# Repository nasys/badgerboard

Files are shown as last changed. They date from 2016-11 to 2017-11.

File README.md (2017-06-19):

				 ___               _                      _                             _
				(  _`\            ( )                    ( )                           ( )
				| (_) )   _ _    _| |   __     __   _ __ | |_      _      _ _  _ __   _| |
				|  _ <' /'_` ) /'_` | /'_ `\ /'__`\( '__)| '_`\  /'_`\  /'_` )( '__)/'_` |
				| (_) )( (_| |( (_| |( (_) |(  ___/| |   | |_) )( (_) )( (_| || |  ( (_| |
			    (____/'`\__,_)`\__,_)`\__  |`\____)(_)   (_,__/'`\___/'`\__,_)(_)  `\__,_)
									 ( )_) |
								 	  \___/'
============================

### **Table of Contents**
 * [Prerequisites](#prerequisites)
 	* [Downloads](#downloads)
	* [General installation](#general-installation)
 	* [Mac OS X installation with Git](#mac-os-x-installation-with-git)
 	* [Windows installation with Git](#windows-installation-with-git)
 * [Badgerboard Setup](#badgerboard-setup)
	* [Test out your Badgerboard](#test-out-your-badgerboard) 
 	* [LoRa sensor setup](#lora-sensor-setup)
 * [Debugging](#debugging)
 * [Known issues](#known-issues)
 * [Version log](#version-log)
 * [Used libraries](#used-libraries)
 * [Licences](#licences)

### Prerequisites

##### Downloads

* [**Arduino**](https://www.arduino.cc/en/Main/Software)
* [**Git**](https://git-scm.com/book/en/v2/Getting-Started-Installing-Git)

#### General installation
* [Download](https://github.com/nasys/badgerboard/archive/master.zip) this library as **.zip** file

now this file is in downloads folder named Badgerboard-master.zip

* Open Arduino and include it under **Sketch -> Include library -> add .zip library**

##### Mac OS X installation with Git

* Open "**Finder**" (Press &#8984;+ Space ) 
* type in "terminal" and open it
* type "cd Documents/Arduino/libraries"
* type "git clone https://github.com/nasys/badgerboard"
* Now when you open up your Arduino and _Badgerboard_ library should appear under **Sketch -> Include library**

##### Windows installation with Git

Coming soon

### **Badgerboard setup**
#### Test out your Badgerboard
```diff
- DO NOT POWER ON WITHOUT ANTENNA! 

```

* Make sure Badgerboard power switch is turned ON ([button towards USB port](https://www.maker.io/-/media/makerio/makerimages/blogs/badgerboard/badgerboard-figure-1.jpg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))
* connect Badgerboard to your PC/Mac 
* Open Arduino
* Open Blink example **Files -> Examples -> 01.Basics -> Blink**
* Make sure you have chosen correct board  **Tools -> Board -> LilyPad Arduino USB** and correct port **Tools -> Port** 
* Change the time(number in milliseconds) inside the brackets after "**delay**" to change the speed of blinking
* To **upload** click on the __right pointing arrow__ on the top-left corner of your Arduino window

In case all of this works then you have successfully uploaded your first program to Badgerboard

#### LoRa sensor setup

* Open **File -> Examples -> Badgerboard -> LoRa_temp_hum**
* Replace examples **devEUI**(16 hex char), **appEUI**(16 hex char) and **appKey**(32 hex char) with the ones that Your LoRaWAN™ solution provider has assigned.([example 1](#example-1)) 
* Upload Your code to Badgerboard

##### example 1

	In Arduino code your devEUI, appEUI and appKey are represented by char array and should look similar to 
	this example
	
	const uint8_t devEUI[8] = {
	0x11, 0x11, 0x22, 0x22,
	0x33, 0x33, 0x44, 0x44
	};

	const uint8_t appKey[16] = {
	0x11, 0x11, 0x11, 0x11,
	0x11, 0x11, 0x22, 0x22,
	0x22, 0x22, 0x22, 0x22,
	0x33, 0x33, 0x33, 0x33
	};

	const uint8_t appEUI[8] = {
	0x11, 0x22, 0x33, 0x44,
	0x55, 0x66, 0x77, 0x88
	};

### Debugging

To see Debugging messages open Serial Monitor **Tools -> Serial Monitor**
#### Known issues

* Take a look under [troubleshooting](https://github.com/nasys/badgerboard/wiki/Troubleshooting) page
* Works only with Arduino version 1.6.10 and later

### Version log

#### Version 0.0.3
	* Added a quickfix related to SF not changeing
	* Added _mod to library names to avoid issues if libraries are already installed
	
#### Version 0.0.2
:calendar:06.12.2016

	* Changed spreading factor changing to automatic
	* Added liquid detection example 

#### Version 0.0.1
:calendar:01.11.2016 

	Initial version of Badgerboard library

#### Used libraries
* [**FaBoHumidity_HTS221**](https://github.com/FaBoPlatform/FaBoHumidity-HTS221-Library)
* [**LowPower**](https://github.com/rocketscream/Low-Power)
* [**Sodaq_RN2483**](https://github.com/SodaqMoja/Sodaq_RN2483)

### **Licences**

All of the source files are distributed under the beerware license except where specified otherwise (i.e. external libraries)
 
#### Contacts
In case you found the instructions incomplete or have any questions regarding Badgerboard library
You can :
* Open new thread under [issues](https://github.com/nasys/badgerboard/issues)
* :e-mail: [contact us](mailto:badgerboard@nasys.no)

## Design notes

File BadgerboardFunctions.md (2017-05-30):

* **badger_init()** -  Mandatory to use badgerboard library.

* ****badger_temp_hum_get(float* temp, float* hum)** - Returns onboard temperature and humidity sensor readings. 

**e.g** 

      void loop() 
        {
          static float temp = 0;
          static float hum = 0;
          badger_temp_hum_get(&temp,&hum);
          Serial.print("temperature  :  ");
          Serial.println(temp);
          Serial.print("humidity  :  ");
          Serial.println(hum);
          delay(4000);
        }

* **Lora_requires_reset()** - If failed packets is greater than 10(_in a row not total_) this function returns true
**_reccommended to use with badger_restart()_**.

* **LoRa_init(const uint8_t dev_EUI[8], const uint8_t app_EUI[8], const uint8_t app_Key[16])** -  Starts communication with LoRa module
**_devEUI, appkey and appEUI_** have to be previously defined.

**e.g**.

        const uint8_t devEUI[8] = {
        0x87, 0x65, 0x43, 0x23,
        0x45, 0x67, 0x87, 0x65
        };

       const uint8_t appKey[16] = {
        0x76, 0x54, 0x32, 0x34,
        0x56, 0x78, 0x98, 0x76,
        0x54, 0x32, 0x23, 0x45,
        0x67, 0x87, 0x65, 0x43
        };

       const uint8_t appEUI[8] = {
       0x65, 0x43, 0x23, 0x45,
       0x67, 0x88, 0x76, 0x54
       };

        void setup()
        {
            badger_init();
           LoRa_init(devEUI, appEUI, appKey);
        }

* **badger_print_EUI(const uint8_t dev_EUI[8])** - Prints devEUI to serial monitor.

* ***LoRa_send(uint8_t fPort, const uint8_t* data, uint8_t len)** - User can use this function to send custom information to custom port.

* ***LoRa_send(uint8_t fPort, const uint8_t* data, uint8_t len, int8_t send_count)** - User can use this function to send custom information to custom port ( send_count defines ammount of retries ).

* **badger_temp_sensor_send()** - Sends temperature and humidity to port 19 as **_JSON_**.

* **badger_hum_send()** - Sends onboard humidity sensor readings to port 4.

* **badger_temp_send()** - Sends onboard temperature sensor readings to port 1.

* **LoRa_add_sensitivity(uint8_t sensitivity)**  - User can force LoRa to use different spreading factor
_example_ is under **file &rarr; Examples &rarr; Badgerboard &rarr; LoRa_sf_change**. This example waits for user numeric input to Serial Monitor from **1 to 6** which change spreading factor correspondingly from **7 to 12**.

* **badger_temp_sensor_send_status(uint8_t status)** - Sends temperature, humidity and voltage readings to port 19 as JSON (gives user opportunity to send custom bytes as status).

* **badger_read_vcc_mv()** - Returns **MCU** LDO regulated supply voltage in milliVolts (not actual battery/external power supply voltage), usually 3300 mV. Useful for end of battery detection.

* **badger_restart()** - Restarts Badgerboard.

* **sendCayanneTempHum()** - Send Cayanne standard packet with temperature and humidity .

* **badger_sleep_now(uint32_t period_ms)** - Put badger to sleep for period_ms on **WDT**.

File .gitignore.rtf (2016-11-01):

# gitignore

.DS_Store
info.plist
scm.plist
text-filter.idx
text-find.idx

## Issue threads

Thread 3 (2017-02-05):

Included copies of FaBo HTS221 and LowPower libraries break compiling of sketches that use the originals

avbentem, 2017-02-05:
The Badgerboard core library includes a copy of https://github.com/FaBoPlatform/FaBoHumidity-HTS221-Library When compiling unrelated other sketches that rely on that library, in an Arduino IDE into which the Badgerboard library has been installed as well (but which do not use the Badgerboard library in the sketch), I get:

    libraries/badgerboard/badger.cpp.o (symbol from plugin): In function `sodaq_wdt_enable(wdt_period)':
    (.text+0x0): multiple definition of `faboHumidity'
    sketch/humidity.ino.cpp.o (symbol from plugin):(.text+0x0): first defined here
    collect2: error: ld returned 1 exit status
    Multiple libraries were found for "FaBoHumidity_HTS221.h"
    Used: /Users/arjan/Arduino/libraries/badgerboard
    Not used: /Users/arjan/Arduino/libraries/FaBo_208_Humidity_HTS221

Also, someone else commented on The Things Network that the same applied to https://github.com/rocketscream/Low-Power:

> I got errors compiling older sketches after installing the badgerboard library because they included some kind of incompatible LowPower library. I had to remove the badgerboard/src/lowpower.h and badgerboard/src/lowpower.cpp file to get my old sketches to work again.

This makes me wonder if it might also apply to https://github.com/SodaqMoja/Sodaq_RN2483

Renaming the copies will probably solve the issue?

Kakuke001, 2017-02-08:
Hi,

Changed the library names (added **_mod**) to fix this issue

Closed 2017-10-09.

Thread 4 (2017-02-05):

Getting "LoRa: warning. Spreading factor not set!", "LoRa: power not set!", "LoRa: datarate not set!"

avbentem, 2017-02-05:
When the first OTAA join fails, the Badgerboard library states:

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

Same for SF11, but not for SF10. EU868.

Kakuke001, 2017-02-08:
Hi,

Uploaded new commit where **LoRa_add_sensitivity()** has now **LoRaBee.wakeUp()** function...right now as a quick fix to this problem i added **LoRaBee.wakeUp()** twice which seemed to fix the problem....i try to get to the bottom of this problem soon

qvs5010, 2018-01-19:
where do you add that to the sketch

i get the same from the Lora_temp_hum sketch.

```
Lora: Adding sensitivity: SF 8
LoRa: warning. Spreading factor not set!
LoRa: power not set!
LoRa: datarate not set!
Lora: Adding sensitivity: SF 9
LoRa: warning. Spreading factor not set!
LoRa: power not set!
LoRa: datarate not set!
Lora: Adding sensitivity: SF 10
LoRa: warning. Spreading factor not set!
LoRa: power not set!
LoRa: datarate not set!
Booting failed.
Badger attempting to restart

```

qvs5010, 2018-01-19:
Ok think I found it

badger.cpp?

But still the same problem

```
bool LoRa_add_sensitivity(uint8_t sensitivity)
{
	LoRaBee.wakeUp();
	LoRaBee.wakeUp();
	sensitivity = sensitivity - 1;
	if(sensitivity > 6)
		sensitivity = 6;
	sensitivity = 5 - sensitivity;
	Serial.print("Lora: Adding sensitivity: SF ");
	Serial.println(12 - sensitivity);
	bool ok = LoRaBee.setSpreadingFactor(12 - sensitivity);
	ok = LoRaBee.setTXPower(15) && ok;
	ok = LoRaBee.setDataRate(sensitivity) && ok;
	return ok;
	}
```

```
Configured onboard temp/humidity sensor.
badger temp/hum sensor
devEUI XX XX XX XX XX
Lora: Adding sensitivity: SF -243
LoRa: Spreading factor set to 12
LoRa: power set to 15
LoRa: datarate not set!
Lora: Adding sensitivity: SF 7
LoRa: Spreading factor set to 7
LoRa: power set to 15
LoRa: datarate set to 5
Lora: Adding sensitivity: SF 8
LoRa: warning. Spreading factor not set!
LoRa: power not set!
LoRa: datarate not set!
Lora: Adding sensitivity: SF 9
LoRa: warning. Spreading factor not set!
LoRa: power not set!
LoRa: datarate not set!
Lora: Adding sensitivity: SF 10
LoRa: warning. Spreading factor not set!
LoRa: power not set!
LoRa: datarate not set!

```

KertIlm, 2018-01-22:
Hi qvs5010,

When did you download Badgerboard library ?
I tried it out but i don't have problem with it ... try downloading the latest library and then try it again.

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

qvs5010, 2018-01-22:
Hi got the badgerbord on Friday, and I downloaded the library from this git hub

https://github.com/nasys/badgerboard/archive/master.zip

I followed the instructions as indicated.

can you email me you library and I can try?

Thanks for the help

KertIlm, 2018-01-22:
Hello again!

I uninstalled my Arduino IDE and downloaded it again(downloaded zip file from the link you provided so there is no version difference) ... also tried it on a windows pc ... all seems to work ... try uninstalling Arduino and download the latest version.

qvs5010, 2018-01-22:
Hi
I' trying now on a new machine, downloading all files again, will update you soon

qvs5010, 2018-01-22:
Hi Still does the same

New Machine, new IDE, new Library

```
Lora: Adding sensitivity: SF 7
LoRa: Spreading factor set to 7
LoRa: power set to 15
LoRa: datarate set to 5
Lora: Adding sensitivity: SF 8
LoRa: warning. Spreading factor not set!
LoRa: power not set!
LoRa: datarate not set!
```

```
Quintins-MBP:libraries quintin$ git clone https://github.com/nasys/badgerboard
Cloning into 'badgerboard'...
remote: Counting objects: 546, done.
remote: Total 546 (delta 0), reused 0 (delta 0), pack-reused 546
Receiving objects: 100% (546/546), 670.95 KiB | 184.00 KiB/s, done.
Resolving deltas: 100% (297/297), done.
```

is it hardware related?

qvs5010, 2018-01-22:
Hi
Tried another pc, the same...

I'm going to cry in the conner,
 :'(

KertIlm, 2018-01-22:
are you using badgerboard example program or your own custom code ? ... All my tests were done on **Lora_temp_hum** exmple.

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

qvs5010, 2018-01-22:
Hi

Yes I load the example directly.

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

qvs5010, 2018-01-22:
Hi

I tried to add more LoRaBee.wakeUp(); to the LoRa_add_sensitivity(uint8_t sensitivity) function, to make it look like the following.

```
bool LoRa_add_sensitivity(uint8_t sensitivity)
{
	LoRaBee.wakeUp();
	LoRaBee.wakeUp();
	LoRaBee.wakeUp();
	LoRaBee.wakeUp();
	sensitivity = sensitivity - 1;
	if(sensitivity > 6)
		sensitivity = 6;
	sensitivity = 5 - sensitivity;
	Serial.print("Lora: Adding sensitivity: SF ");
	Serial.println(12 - sensitivity);
	bool ok = LoRaBee.setSpreadingFactor(12 - sensitivity);
	ok = LoRaBee.setTXPower(15) && ok;
	ok = LoRaBee.setDataRate(sensitivity) && ok;
	return ok;
	}
```

must I compile the cpp file after changing or will the IDE do that?

qvs5010, 2018-01-22:
Hi

Even with the extra LoRaBee.wakeUp(); still the same

```
Configured onboard temp/humidity sensor.
badger temp/hum sensor
devEUI 11 11 22 22 33 33 44 44
Lora: Adding sensitivity: SF -243
LoRa: Spreading factor set to 12
LoRa: power set to 15
LoRa: datarate not set!
Lora: Adding sensitivity: SF 7
LoRa: Spreading factor set to 7
LoRa: power set to 15
LoRa: datarate set to 5
Lora: Adding sensitivity: SF 8
LoRa: warning. Spreading factor not set!
LoRa: power not set!
LoRa: datarate not set!
```

KertIlm, 2018-01-22:
Have you chosen **LilyPad Arduino USB** as board

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

qvs5010, 2018-01-22:
Hi

yes, I'm the Lilly USB

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

qvs5010, 2018-01-22:
I can give you access to my pc is you want.

KertIlm, 2018-01-22:
send me e-mail kert.ilm@nasys.no

qvs5010, 2018-01-22:
Got it. you can remove you email if you want, will send it through now

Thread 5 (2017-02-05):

badger_temp_sensor_send and badger_temp_sensor_send_status should not send JSON and not use confirmed uplinks

avbentem, 2017-02-05:
Sending JSON is just a waste of bandwidth, and so is using confirmed uplinks for all data.

https://github.com/nasys/badgerboard/blob/a2b1dfe1d00efa44664a8a5b05fd8074b4d61771/src/badger.cpp#L533-L587

Something like the following will do just fine; the backend application can easily decode it if documented.

    // Reserve 6 bytes (3 words) to send temperature, humidity and voltage
    byte data[6];

    double temp = faboHumidity.getTemperature();
    double humi = faboHumidity.getHumidity();

    // Encode the 2 doubles into the first 4 bytes
    int temp = 100 * hts221.getTemperature();
    int humi = 100 * hts221.getHumidity();
    data[0] = temp >> 8; // or: highByte(temp)
    data[1] = temp; // or: lowByte(temp)
    data[2] = humi >> 8;
    data[3] = humi;
    // For some reason the core library uses port 19; please document!
    return LoRa_send(19, (uint8_t*) data, 4, NO_ACK);
    ...
    long voltage = badger_read_vcc_mv();
    data[4] = voltage >> 8;
    data[5] = voltage;
    // One could use a different port here
    return LoRa_send(19, (uint8_t*) data, 6, NO_ACK);

(I'd argue that sending the values should be part of the core library at all. For decoding the above see also [Getting Badgerboard to work with TTN](https://www.thethingsnetwork.org/forum/t/getting-badgerboard-to-work-with-ttn/5224).)

Kakuke001, 2017-02-08:
Hi,

Status packet is not meant to be sent very often and is meant rather as keepalive packet, thus its confirmed. Since Badgerboard is meant mostly for making proof-of-concepts, and JSON is simply human readable, we started with it. But we will add similar function You proposed.

avbentem, 2017-02-08:
As far as I can tell from the code, the status message [is sent unconfirmed](https://github.com/nasys/badgerboard/blob/7176e1404468bf8781a3f394bac1c8d49418f77f/src/badger.cpp#L593), but the regular message [uses the default](https://github.com/nasys/badgerboard/blob/7176e1404468bf8781a3f394bac1c8d49418f77f/src/badger.cpp#L545), and [your default is to send confirmed messages](https://github.com/nasys/badgerboard/blob/7176e1404468bf8781a3f394bac1c8d49418f77f/src/badger.cpp#L401-L414).

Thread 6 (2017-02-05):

Document that the RN2483 module needs reset after uploading sketch or restarting board

avbentem, 2017-02-05:
Apparently one needs to reset the RN2483 after powering or flashing the board, otherwise it will just not respond to any command sent through, e.g., `Serial1.write` or `loraSerial.write`.

The library takes care of that by calling [its own `badger_reset_lora`](https://github.com/nasys/badgerboard/blob/a7855d1c1b1d4c4c1c219d42e43ff60c309b21a6/src/badger.cpp#L662-L668); it would be nice to document this for those who want to use different libraries, such as the one from The Things Network.

```
#define LORA_RESET_PIN 5
void badger_reset_lora()
{
	pinMode(LORA_RESET_PIN, OUTPUT);
	digitalWrite(LORA_RESET_PIN, LOW);
        // Can one just use delay(15) instead?
	sleep_wdt_approx(15);
	digitalWrite(LORA_RESET_PIN, HIGH);
}
```

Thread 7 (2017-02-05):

Document what badger_read_vcc_mv is measuring and if the RN2483 Vdd is connected

avbentem, 2017-02-05:
I assume [the `badger_read_vcc_mv` function](https://github.com/nasys/badgerboard/blob/a2b1dfe1d00efa44664a8a5b05fd8074b4d61771/src/badger.cpp#L733-L758) is measuring the LiPo connector (which I cannot test right now). When using the USB port, or when connecting a battery pack to `Vin` and `GND`, I always get 3.339 for the Badgerboard function, and always 3.283 for the response of the RN2483 `sys get vdd` command. (Another Badgerboard always reports 3.41 for the Badgerboard function and 3.325 for `Vdd`.)

The `sys get vdd` command is [documented by Microchip as](http://ww1.microchip.com/downloads/en/DeviceDoc/40001784B.pdf#page=16):

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

[Badgerboard's technical specifications](http://badgerboard.io/wp-content/uploads/2016/11/Badgerboard_UX2001A.pdf) do not indicate if it's connected.

Please document what `badger_read_vcc_mv` is measuring, and if the RN2483's `Vdd` is connected.

Kakuke001, 2017-02-08:
HI,

Function badger_read_vcc_mv() does not measure LiPo voltage... this function measures MCU supply voltage (after LDO) so this can't be over 3.3  but it starts falling if battery is emptying until 2.7V which is marked as MCU minimum operating voltage

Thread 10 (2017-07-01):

Have I bricked my Badgerboard

patmolloy, 2017-07-01:
Has been working perfectly. But I uploaded a new sketch earlier and now get USB Device unrecognised on my Win10 machine (and several others). The upload has upset something, presumably whatever deals with the USB on the badgerboard.

Arduino IDE no longer can see any COM port associated with the badgerboard.

Any way to recover?

patmolloy, 2017-07-01:
Ok, I somehow nixed the bootloader .. somewhat out of my depth but followed the guide here https://learn.sparkfun.com/tutorials/installing-an-arduino-bootloader and am alive again. Incidentally the USB stuff is *within* the ATMEGA32U4. I ended up installing USBasp as the programmer and using the Arduino IDE (1.8.3) to "Burn Bootloader" having selected "Lilypad Arduino USB" as the device.

rmh78, 2017-07-04:
Thanks a lot, your hint worked for me too!

patmolloy, 2017-07-04:
Yay! Painful, but always good to learn a bit more :)

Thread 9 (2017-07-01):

Arduiono IDE upload not working any more

rmh78, 2017-07-01:
I developed my arduino program and uploaded it all the time without problems.
After one upload it did not work any more.

The arduino IDE showed this error message:
avrdude: butterfly_recv(): programmer is not responding
Found programmer: Id = "Configu"; type = A
    Software Version =  .�; Hardware Version = O.T
avrdude: error: buffered memory access not supported. Maybe it isn't
a butterfly/AVR109 but a AVR910 device?
avrdude: initialization failed, rc=-1
         Double check connections and try again, or use -F to override
         this check.

avrdude: error: programmer did not respond to command: leave prog mode
avrdude: error: programmer did not respond to command: exit bootloader

Do you have any idea what happened to my badgerboard?

rmh78, 2017-07-01:
If I open the seriell monitor I see that my last uploaded program is still running.
But I'm not able to upload any other program. I also tried the simple blick example (same error).

rmh78, 2017-07-04:
Like @patmolloy wrote in his issue I read the article "Installing an Arduino Bootloader" on https://learn.sparkfun.com/tutorials/installing-an-arduino-bootloader and gave it a try.

1) I used my Arduino UNO as a programmer and uploaded the sketch ArduinoISP to it.
2) I connected the Badgerboard to the Arduino UNO as described in the article
3) In the Arduino IDE I choose as Board "LilyPad Arduino USB" and called "Burn Bootloader"

And everything worked fine and I'm able to upload sketches again :-)

Thanks to @patmolloy for this hint!

Closed 2017-07-04.

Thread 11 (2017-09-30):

Document how the charging LED works, and where the LEDs and sensors are located

avbentem, 2017-09-30:
There's a green LED on the board that is apparently related to charging. When connected to an USB charger, sometimes it's green, sometimes it's just off. I've not tested with the V<sub>in</sub> pin.

- It would be nice to document what, e.g., a green light means, and if one can determine if charging is complete.
- It would be nice to enhance the data sheet and/or pinout diagram to document its position on the printed circuit board.
- It would also be nice to document the position of the other components on that data sheet/pinout diagram, such as the on/off switch, the reset button, the TX/RX LEDs, and the sensors. Like in the image below, as found on https://www.kickstarter.com/projects/badgerboard/badgerboard-your-ticket-to-the-lora-world

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

KertIlm, 2017-10-09:
Hello,
Added this image to https://github.com/nasys/badgerboard/blob/master/schematics/badgerPinout.png
You can also check out [badgerboard home page](http://badgerboard.io) for additional information.

*  Yes, the charging led “goes mad” when no battery is connected this happens because pins are left floating.
*  Green light near battery connector means that the battery is charging
*  It does not matter if the power switch is on or off since the led is directly to Vin and usb “Plus” pins
Since design files are public I see no need to bring out battery connections and other components

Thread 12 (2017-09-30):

Misplaced top silkscreen layer

skabashnyuk, 2017-09-30:
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

skabashnyuk, 2017-10-07:
Any comments? Is this expected or it's just mine local problem?

KertIlm, 2017-10-09:
Hello,
This is not your problem since silkscreen is not used by Nordic Automation Systems. Due to that reason they don't pay attention to this layer. The components are tiny and side-by-side thus it makes no sense to label them on PCB especially when design files are public so everyone can just check them from there.

Closed 2017-10-09.

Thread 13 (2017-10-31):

Attach radio TX to interrupt

tomhelmer, 2017-10-31:
Are there a way to connect the radio TX pin to an interrupt pin ?

I would like the radio board to wake up the system after sleep.

Example: http://tinkerman.cat/low-power-in-lorawan-world-meet-the-rn2483/

Closed 2020-06-22.

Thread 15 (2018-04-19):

hc-sr04

qvs5010, 2018-04-19:
Hi

is it posible to to use the hc-sr04 sensor with the badgerboard?

Thanks

KertIlm, 2018-04-19:
Hi qvs5010,

Short answer is YES. If you can find an Arduino guide like [this](https://howtomechatronics.com/tutorials/arduino/ultrasonic-sensor-hc-sr04/) then you most likely can also build it on badgerboard ... just make sure you have the correct pins from [here](http://badgerboard.io/wp-content/uploads/2017/02/badgerboard_pinout.pdf).
Biggest exception is that you can't use hardware uart because it is connected directly to RN2483(2903) module.

qvs5010, 2018-04-19:
Hi Kertllm

Thanks

I have found the Badgerboard  //drowning sensor example where you use the following pins

void setup()
```
{
    pinMode(A0,OUTPUT);  // Physical pi A0 on the board ?
    pinMode(A1,INPUT);
    digitalWrite(A0,LOW); // Pin A0 |   LOW is off / HIGH is on ?
    digitalWrite(A1,LOW); // Pin A1
.......
```
So I can use Boardpin A0 for TrigPin (Output) and then Boardpin A1 for EchoPin (Input)

```
bool testDist() //read analog value of sensor
{
    digitalWrite(A0,HIGH);
    delayMicroseconds(10);
    digitalWrite(A0,LOW);

    duration = pulseIn(digitalWrite(A1,HIGH));
    distance= duration*0.034/2;

    Serial.println(distance);
    return distance;

}

```
Sensor      BadgerBoard
Ground -   Ground Pin
VCC -         3.3V Pin
Trig -          A0 Pin
Echo -        A1 Pin

qvs5010, 2018-05-05:
Hi

I having some issues getting the badger board to talk to the sensor.

I tried all the ports, but no. luck.

What 2 pins can i use on the board for this sensor?

http://badgerboard.io/wp-content/uploads/2017/02/badgerboard_pinout.pdf

qvs5010, 2018-05-05:
Hi

this is the code i'm using, i removed all the lora code for now, just to get the sensor going.

```
// defines pins numbers
const int trigPin = 9;
const int echoPin = 10;
// defines variables
long duration;
int distance;

void setup()
{

    pinMode(trigPin, OUTPUT); // Sets the trigPin as an Output
    pinMode(echoPin, INPUT); // Sets the echoPin as an Input

    //badger_init();
    //Serial.println("badger temp/hum sensor");
    //badger_print_EUI(devEUI);
    //LoRa_init(devEUI, appEUI, appKey,true);

}

void loop()
{
    badger_pulse_led(1);
    // Clears the trigPin
    digitalWrite(trigPin, LOW);
    delayMicroseconds(2);
    // Sets the trigPin on HIGH state for 10 micro seconds
    digitalWrite(trigPin, HIGH);
    delayMicroseconds(10);
    digitalWrite(trigPin, LOW);
    // Reads the echoPin, returns the sound wave travel time in microseconds
    duration = pulseIn(echoPin, HIGH);
    Serial.println(duration);
    // Calculating the distance
    distance = duration*0.034/2;
    // Prints the distance on the Serial Monitor
    Serial.print("Distance: ");
    Serial.println(distance);

    //if(temp_sched.run_now())
    //{
        // this function is called when the time defined at the "temp_sched" variable is reached
        //badger_pulse_led(1);

        //badger_blink_error(badger_temp_sensor_send());
    //}
    //temp_sched.print_soonest();
    if(Lora_requires_reset())
    {
        badger_restart();
    }
    //badger_sleep_now(s_badger_sleep_period_ms);
}
```
On the Console my echo pin only read 4 regardless how far the sensor is, if i unplug the echo port i get 0,

I think i have the right pins.

KertIlm, 2018-05-08:
Hi,

I tested it out myself and i got same results as you. I looked at the sensor and saw [that is a 3-5.5 vdc](https://www.geekbuying.com/item/HC-SR04-Ultrasonic-Sensor-Distance-Measuring-Module-3-3V---5V-Compatible-for-Arduino-NodeMCU-360876.html) sensor. I tested it out but it did not work with 3.3 vdc. If you power badgerboard via USB then you can use Vin pin to get ~5 vdc out from there... since echo pin outputs 5 vdc you have to build a voltage divider from echo pin to badgerboard([divide 5 volts to 3.3](http://www.ohmslawcalculator.com/voltage-divider-calculator)).

qvs5010, 2018-05-08:
Hi K

Thanks for the reply

I figure I need the devider, lol.
I just need to get the resistors this week then will do another test.

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

qvs5010, 2018-05-16:
Hi K

I got some resistors and all is working now, Thanks!!

Was a major learning curve on giop's lol.

Closed 2018-05-16.

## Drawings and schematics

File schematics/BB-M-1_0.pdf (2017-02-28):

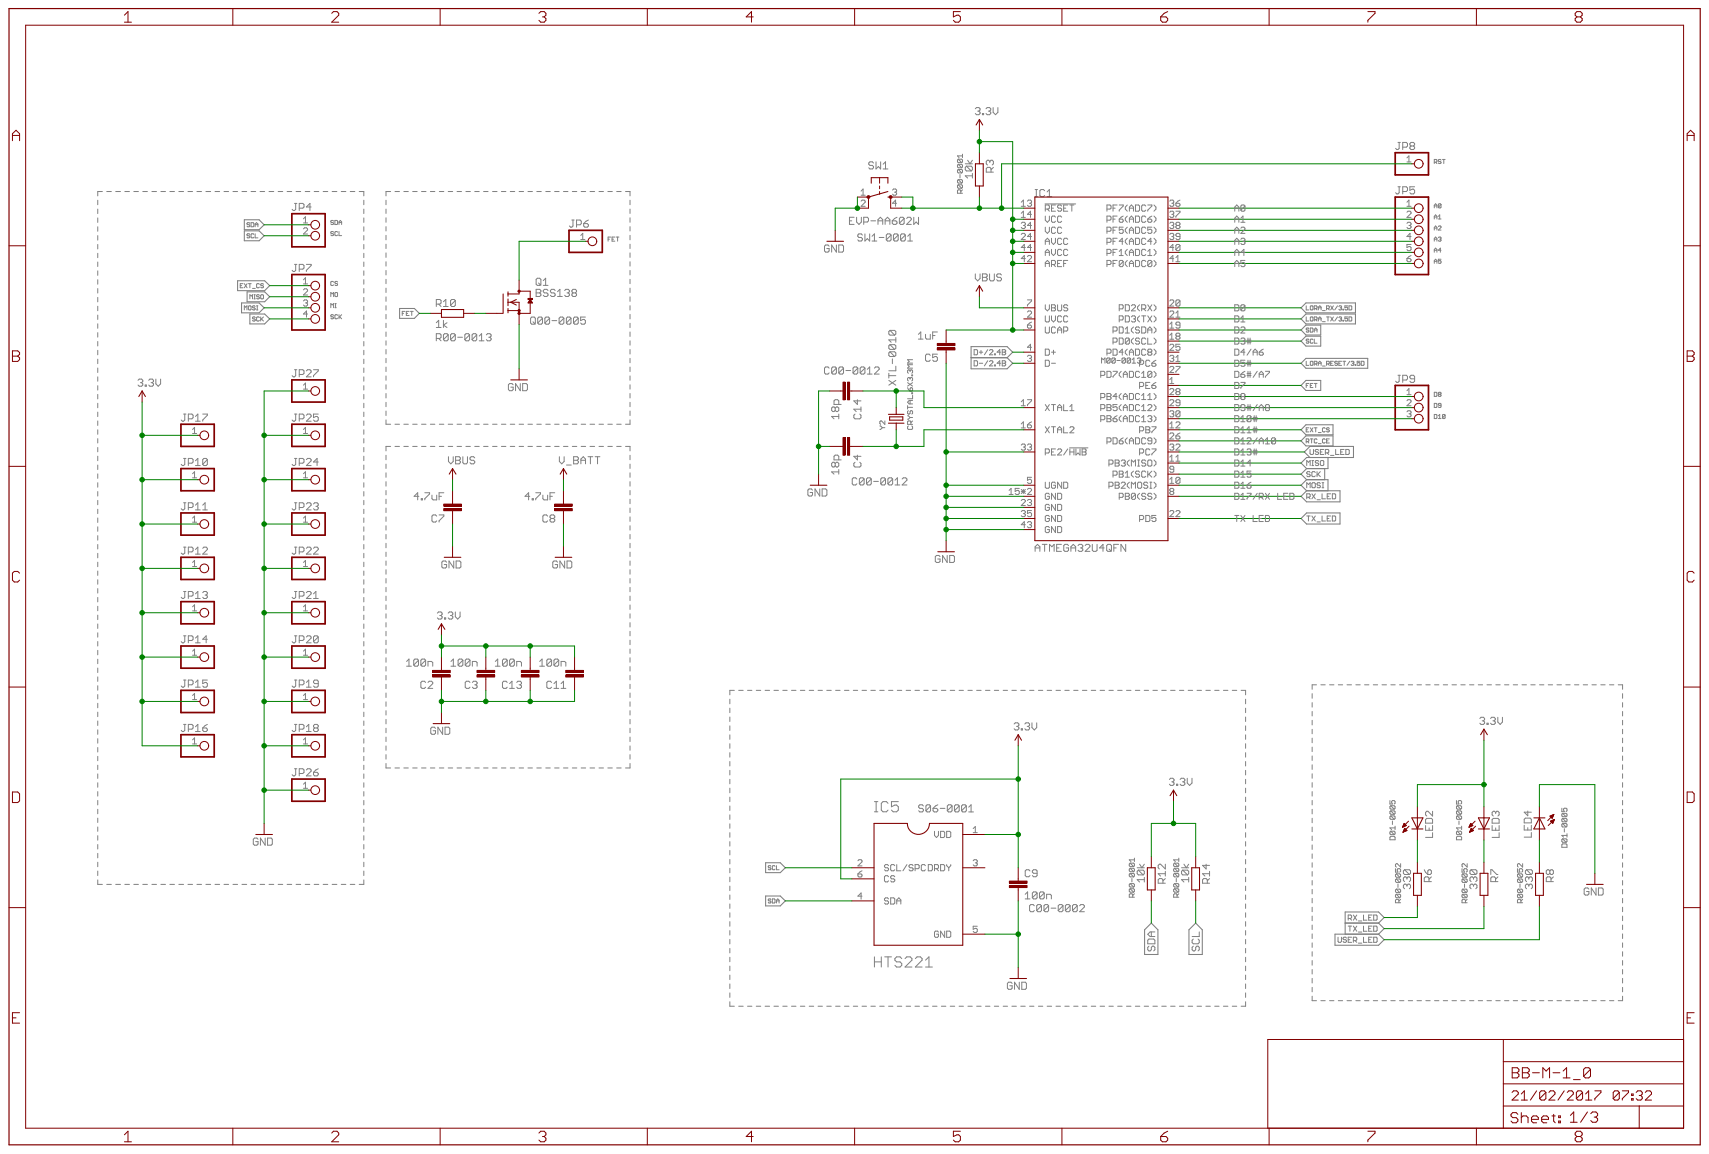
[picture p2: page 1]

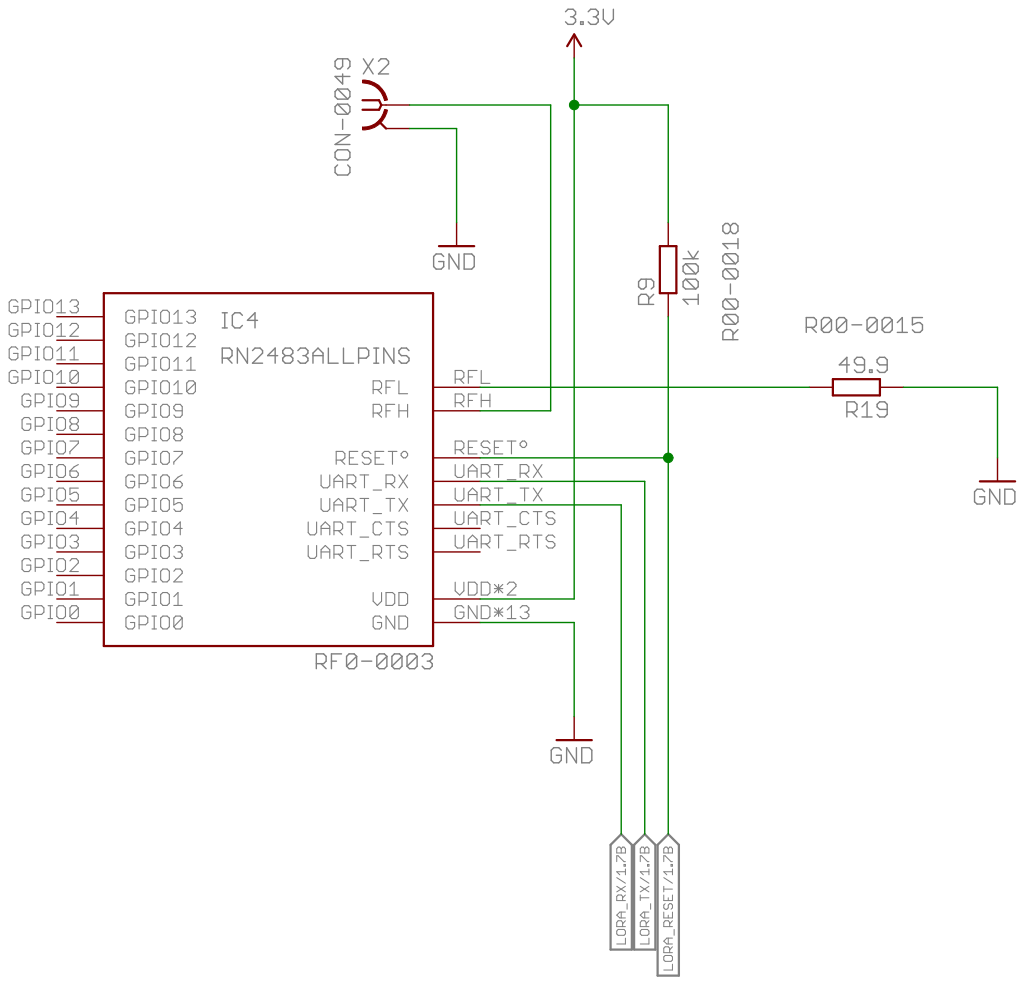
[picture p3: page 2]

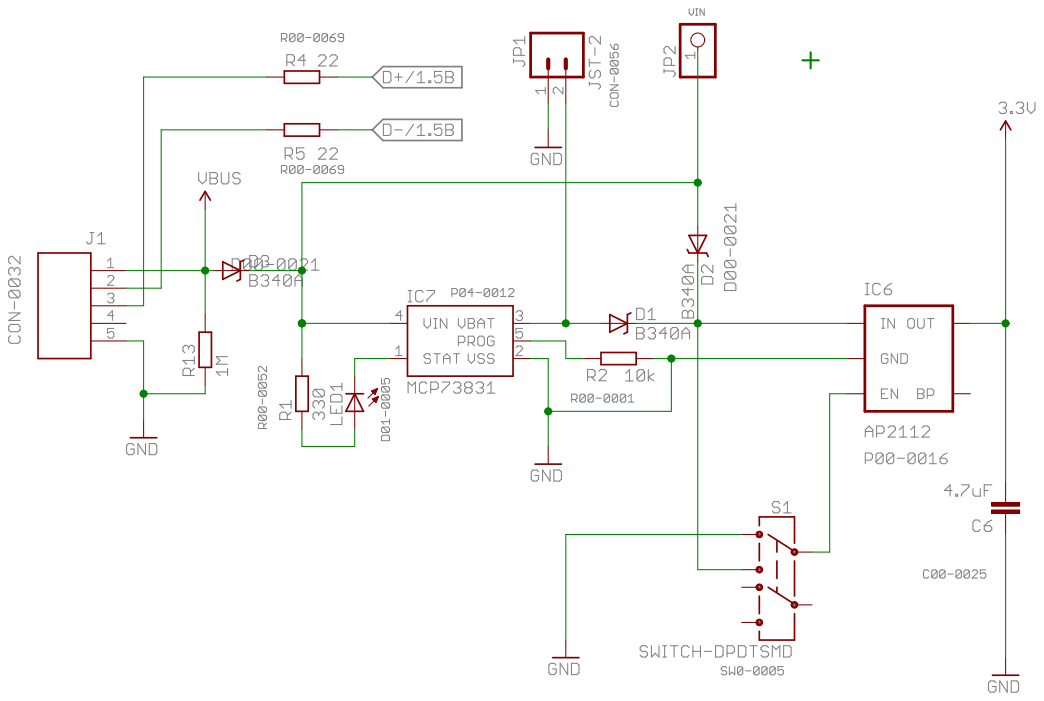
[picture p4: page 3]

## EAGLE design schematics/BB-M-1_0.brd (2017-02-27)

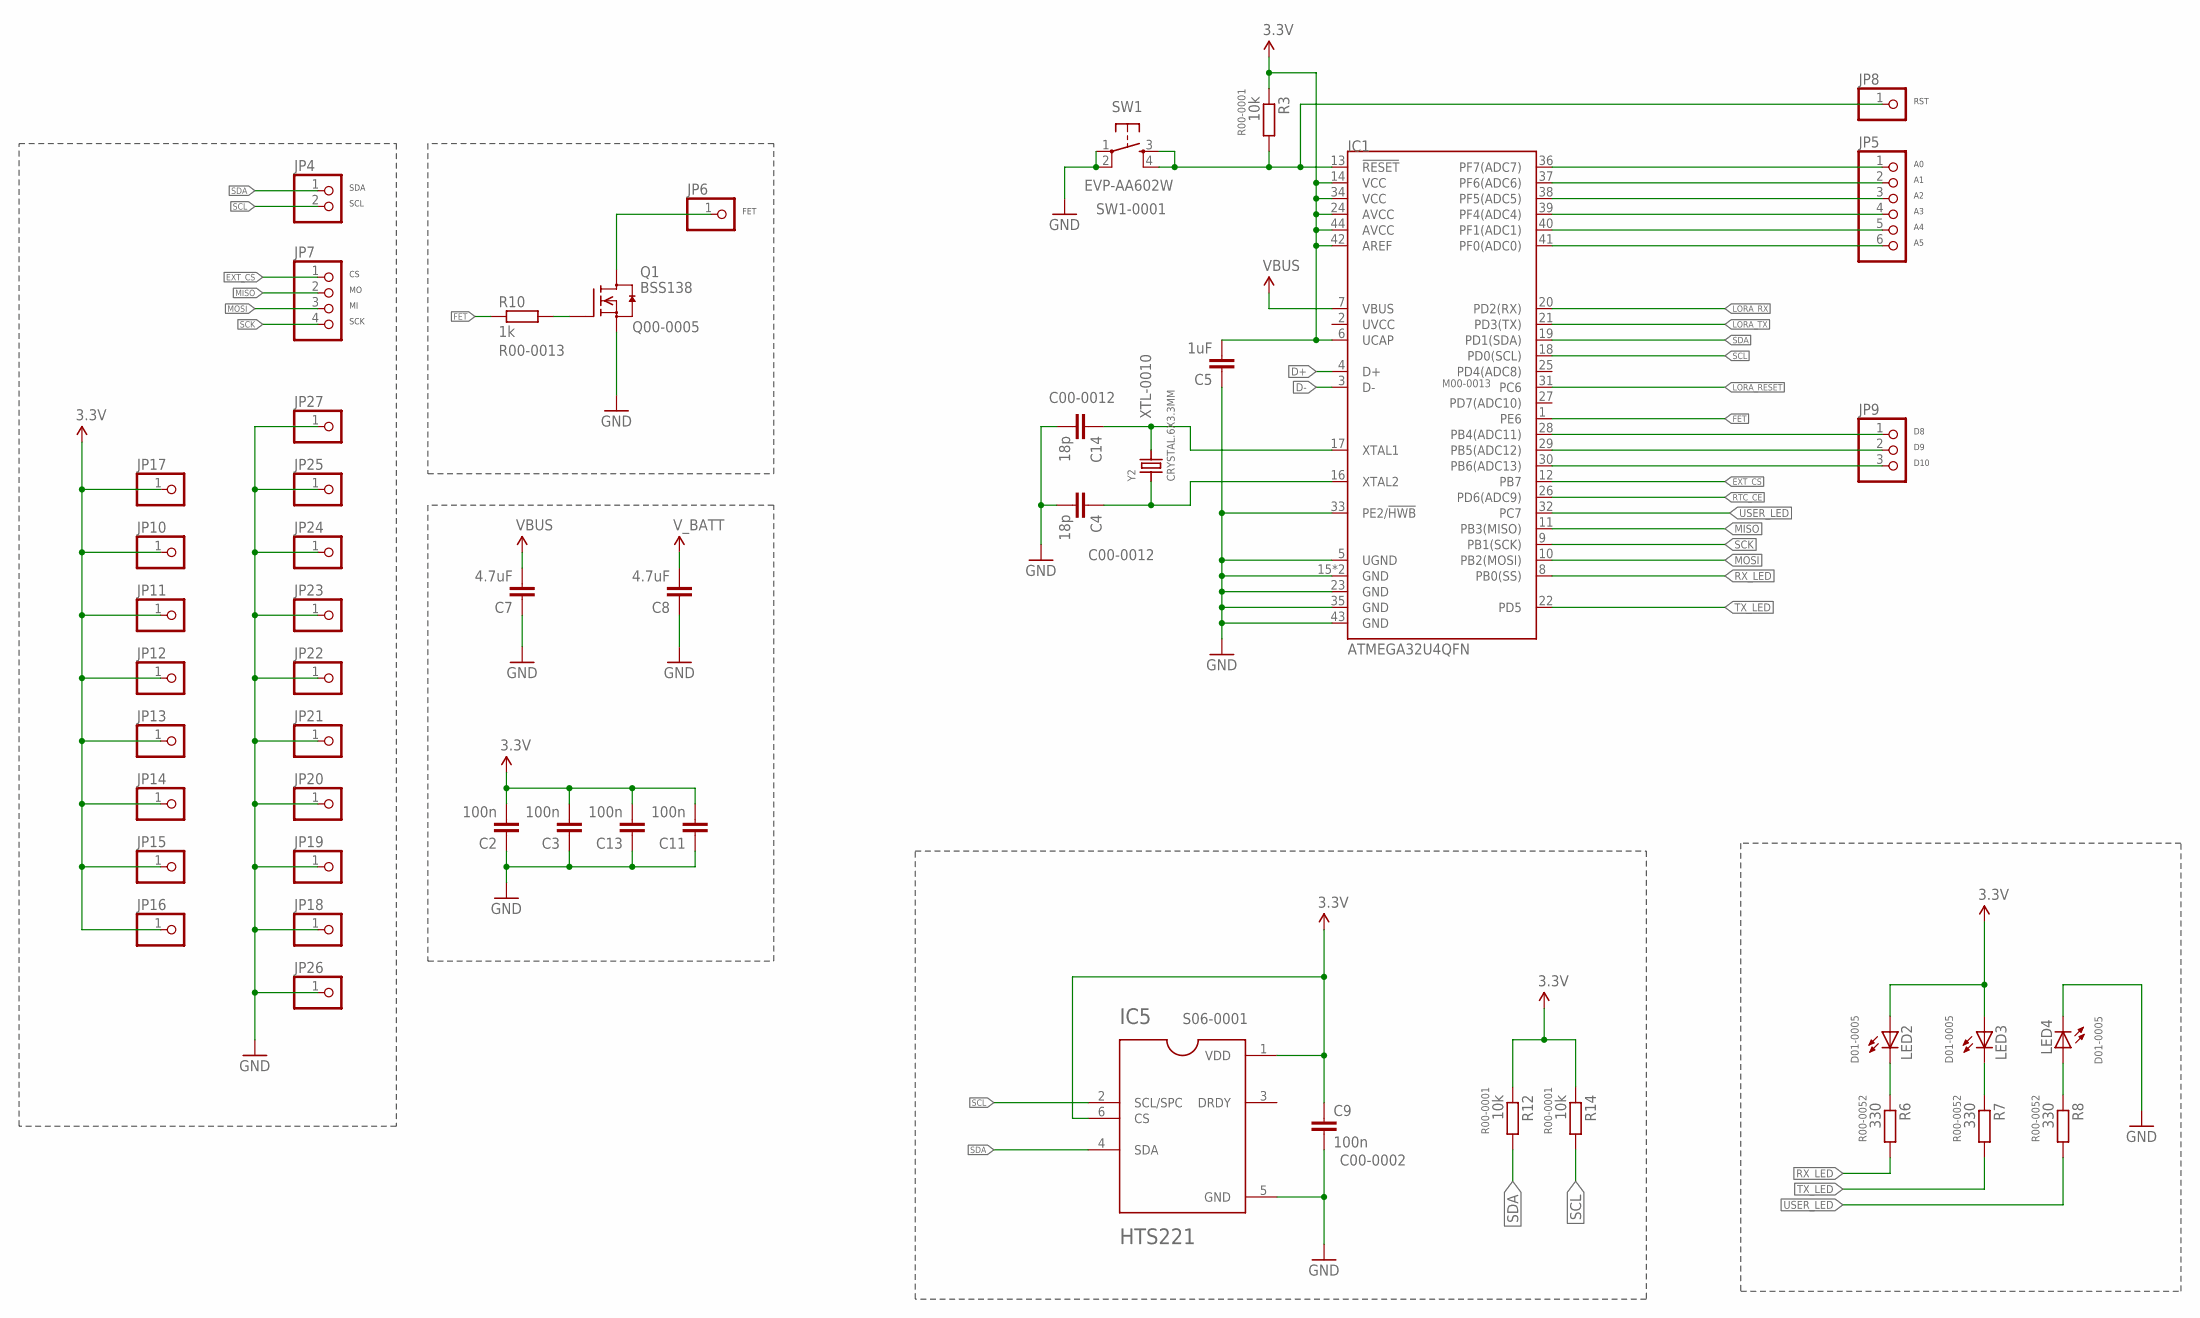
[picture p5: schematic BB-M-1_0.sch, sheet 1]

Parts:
C2, C3, C9, C11, C13: 100n; C0402
C4, C14: 18p; C0402
C5: 1uF; C0402
C7, C8: 4.7uF; C0603
IC1: ATMEGA32U4QFN; QFN-44
IC5: HTS221; LGA6R75P3X2_200X200X90
JP4: HEADER-1X2ROUND; 1X02_ROUND
JP5: HEADER-1X6ROUND; 1X06_ROUND
JP6, JP8, JP10, JP11, JP12, JP13, JP14, JP15, JP16, JP17, JP18, JP19, JP20, JP21, JP22, JP23, JP24, JP25, JP26, JP27: HEADER-1X1ROUND; 1X01_ROUND
JP7: HEADER-1X4ROUND; 1X04_ROUND
JP9: HEADER-1X3ROUND; 1X03_ROUND
LED2, LED3, LED4: LED0603; LED-0603
Q1: BSS138; SOT23
R3, R12, R14: 10k; R0402
R6, R7, R8: 330; R0402
R10: 1k; R0402
SW1: EVP-AA602W; UUS_BUTTON
Y2: CRYSTAL.6X3.3MM; 6X3.3MM

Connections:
3.3V: C2.2, C3.2, C5.2, C9.1, C11.2, C13.2, IC1.6 (UCAP), IC1.14 (VCC), IC1.24 (AVCC), IC1.34 (VCC), IC1.42 (AREF), IC1.44 (AVCC), IC5.1 (VDD), IC5.6 (CS), JP10.1, JP11.1, JP12.1, JP13.1, JP14.1, JP15.1, JP16.1, JP17.1, LED2.A, LED3.A, R3.1, R12.1, R14.1; also elsewhere on the board
5V: C7.2, IC1.7 (VBUS); also elsewhere on the board
D+: IC1.4 (D+); also elsewhere on the board
D-: IC1.3 (D-); also elsewhere on the board
EXT_CS: IC1.12 (PB7), JP7.1
FET: IC1.1 (PE6), R10.1
FET_OUTPUT: JP6.1, Q1.3 (D)
GND: C2.1, C3.1, C4.2, C5.1, C7.1, C8.1, C9.2, C11.1, C13.1, C14.2, IC1.5 (UGND), IC1.15 (GND), IC1.23 (GND), IC1.33 (PE2/!HWB), IC1.35 (GND), IC1.43 (GND), IC1.EPAD (GND), IC5.5 (GND), JP18.1, JP19.1, JP20.1, JP21.1, JP22.1, JP23.1, JP24.1, JP25.1, JP26.1, JP27.1, LED4.C, Q1.2 (S), SW1.1, SW1.2 (P1); also elsewhere on the board
LORA_RESET: IC1.31 (PC6); also elsewhere on the board
LORA_RX: IC1.20 (PD2(RX)); also elsewhere on the board
LORA_TX: IC1.21 (PD3(TX)); also elsewhere on the board
MISO: IC1.11 (PB3(MISO)), JP7.2
MOSI: IC1.10 (PB2(MOSI)), JP7.3
unnamed: LED2.C, R6.1
unnamed: C14.1, IC1.17 (XTAL1), Y2.2
unnamed: C4.1, IC1.16 (XTAL2), Y2.1
unnamed: IC1.30 (PB6(ADC13)), JP9.3
unnamed: IC1.29 (PB5(ADC12)), JP9.2
unnamed: Q1.1 (G), R10.2
unnamed: IC1.36 (PF7(ADC7)), JP5.1
unnamed: IC1.41 (PF0(ADC0)), JP5.6
unnamed: IC1.40 (PF1(ADC1)), JP5.5
unnamed: IC1.39 (PF4(ADC4)), JP5.4
unnamed: IC1.38 (PF5(ADC5)), JP5.3
unnamed: LED4.A, R8.1
unnamed: LED3.C, R7.1
unnamed: IC1.37 (PF6(ADC6)), JP5.2
unnamed: IC1.28 (PB4(ADC11)), JP9.1
RESET: IC1.13 (!RESET), JP8.1, R3.2, SW1.3 (S), SW1.4 (S1)
RTC_CE: IC1.26 (PD6(ADC9))
RX_LED: IC1.8 (PB0(SS)), R6.2
SCK: IC1.9 (PB1(SCK)), JP7.4
SCL: IC1.18 (PD0(SCL)), IC5.2 (SCL/SPC), JP4.2, R14.2
SDA: IC1.19 (PD1(SDA)), IC5.4 (SDA), JP4.1, R12.2
TX_LED: IC1.22 (PD5), R7.2
USER_LED: IC1.32 (PC7), R8.2
V_BATT: C8.2; also elsewhere on the board

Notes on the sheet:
SDA
SCL
SCK
FET
RST
D10

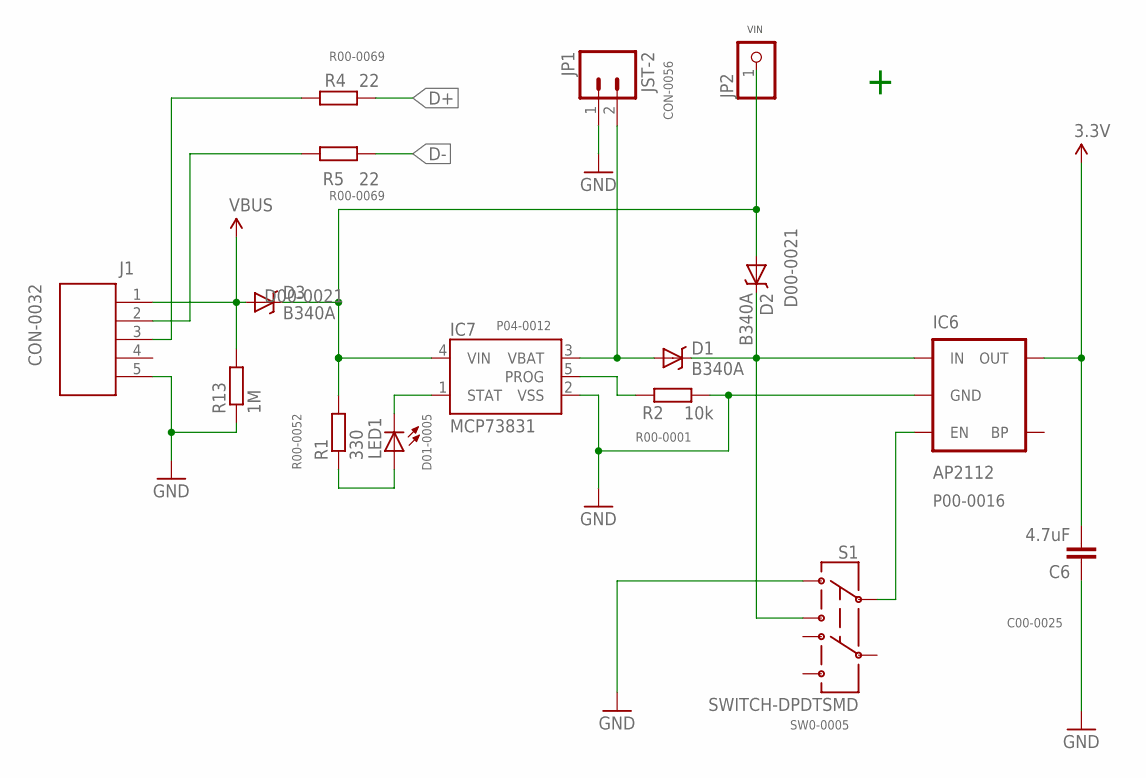
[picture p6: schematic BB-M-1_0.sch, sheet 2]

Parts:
C6: 4.7uF; C0603
D1, D2, D3: B340A; SMA-DIODE
IC6: AP2112; SOT23-5
IC7: MCP73831; SOT23-5
J1: 629105136821
JP1: JST-2; JST-2-SMD
JP2: PINHD-1X1CB; 1X01-CLEANBIG
LED1: LED0603; LED-0603
R1: 330; R0402
R2: 10k; R0402
R4, R5: 22; R0402
R13: 1M; R0402
S1: SWITCH-DPDTSMD; AYZ0202

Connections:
3.3V: C6.2, IC6.5 (OUT); also elsewhere on the board
5V: D3.A, J1.1, R13.2; also elsewhere on the board
D+: R4.1; also elsewhere on the board
D-: R5.1; also elsewhere on the board
GND: C6.1, IC6.2 (GND), IC7.2 (VSS), J1.5, JP1.1 (2), R2.1, R13.1, S1.1; also elsewhere on the board
unnamed: D1.C, D2.C, IC6.1 (IN), S1.3
unnamed: LED1.A, R1.1
unnamed: IC7.1 (STAT), LED1.C
unnamed: IC7.5 (PROG), R2.2
unnamed: IC6.3 (EN), S1.2
unnamed: J1.2, R5.2
unnamed: J1.3, R4.2
unnamed: D2.A, D3.C, IC7.4 (VIN), JP2.1, R1.2
V_BATT: D1.A, IC7.3 (VBAT), JP1.2 (1); also elsewhere on the board

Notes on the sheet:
VIN

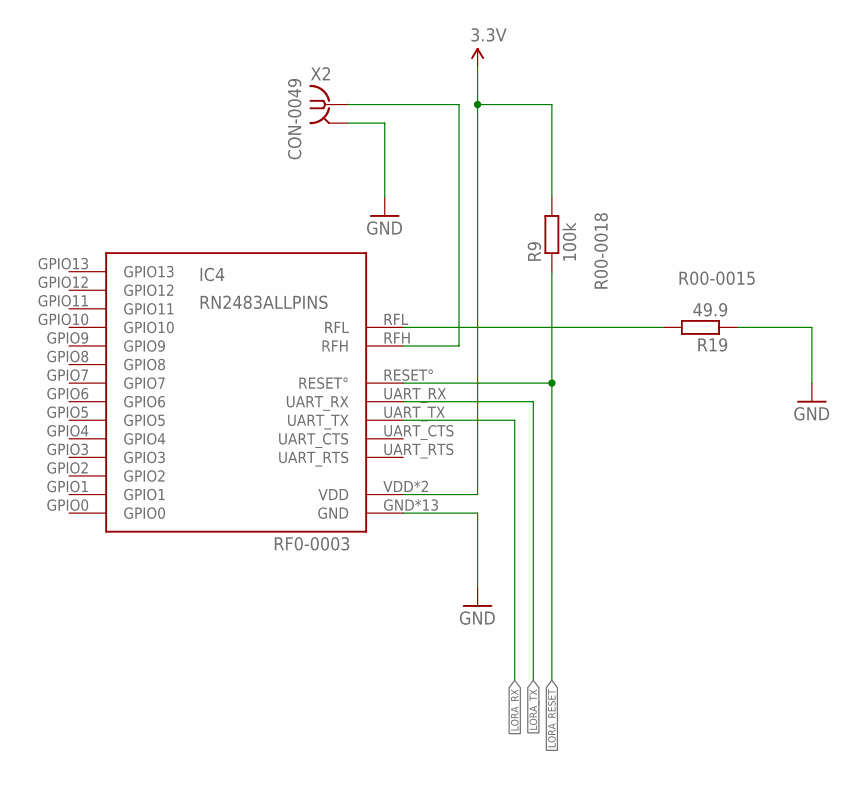
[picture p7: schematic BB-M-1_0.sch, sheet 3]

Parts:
IC4: RN2483ALLPINS; RN2483
R9: 100k; R0402
R19: 49.9; R0402
X2: 132414

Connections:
3.3V: IC4.VDD, IC4.VDD2 (VDD), R9.2; also elsewhere on the board
GND: IC4.GND, IC4.GND1 (GND), IC4.GND2 (GND), IC4.GND3 (GND), IC4.GND4 (GND), IC4.GND5 (GND), IC4.GND6 (GND), IC4.GND7 (GND), IC4.GND8 (GND), IC4.GND9 (GND), IC4.GND10 (GND), IC4.GND11 (GND), IC4.GND12 (GND), R19.1, X2.G@1 (GND), X2.G@2 (GND), X2.G@3 (GND), X2.G@4 (GND); also elsewhere on the board
LORA_RESET: IC4.RESET°, R9.1; also elsewhere on the board
LORA_RX: IC4.UART_TX; also elsewhere on the board
LORA_TX: IC4.UART_RX; also elsewhere on the board
unnamed: IC4.RFL, R19.2
unnamed: IC4.RFH, X2.1

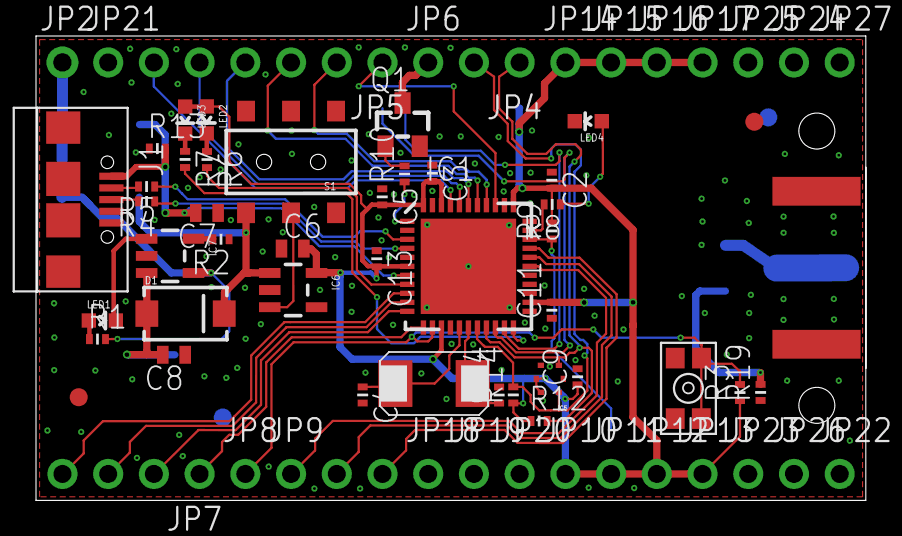
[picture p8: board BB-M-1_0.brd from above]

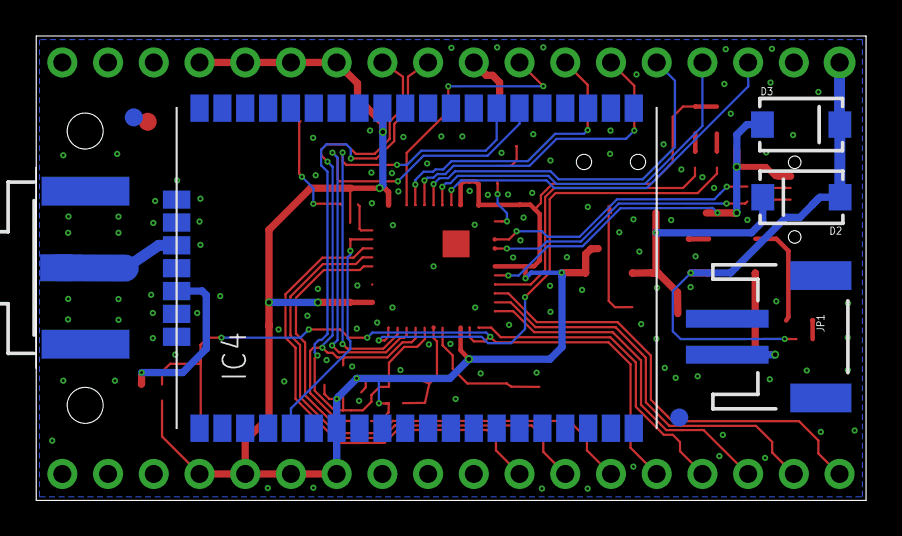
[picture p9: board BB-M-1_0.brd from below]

Board: 2 copper layers, 46.1 x 25.8 mm, 73 parts (7 on the bottom side), 46 nets.

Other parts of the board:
U$1, U$2, U$3, U$4: FIDUCIAL_L10

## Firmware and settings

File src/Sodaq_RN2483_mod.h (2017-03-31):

/*
* Copyright (c) 2015 SODAQ. All rights reserved.
*
* This file is part of Sodaq_RN2483.
*
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
* You should have received a copy of the GNU Lesser General Public
* License along with Sodaq_RN2483.  If not, see
* <http://www.gnu.org/licenses/>.
*/

#ifndef _Sodaq_RN2483_h
#define _Sodaq_RN2483_h

#include <Arduino.h>

#include <stdint.h>
#include <Stream.h>
#include "Switchable_Device_mod.h"

/**

 Notes:

 - uint16_t is preferred over size_t because long is never needed by the
   size of the packets or the buffers of this application.
   (Kees Bakker does not agree with this. size_t is not the same as long.
    On AVR a size_t is uint16_t. On SAMD we don't care too much about the
    data size, a long is fine.)
 - Currently, only one received packet is supported. Every time a packet is
   received, the previous one is overwritten.
 - Also multiple responses from the server (with Frame Pending Bit set) are
   not supported.
 - The port of the received packet is not returned.

 */

//#define USE_DYNAMIC_BUFFER

//#define DEBUG

#define ENABLE_SLEEP

#define DEFAULT_BAUDRATE 57600
//#define DEFAULT_BAUDRATE 19200
//#define DEFAULT_BAUDRATE 9600
#define DEFAULT_INPUT_BUFFER_SIZE 64
#define DEFAULT_RECEIVED_PAYLOAD_BUFFER_SIZE 32
#define DEFAULT_TIMEOUT (120 * 3)
#define RECEIVE_TIMEOUT 60000
#define DEFAULT_FSB 2

#if defined(ARDUINO_ARCH_AVR)
typedef HardwareSerial SerialType;
#define ENABLE_SLEEP
#elif defined(ARDUINO_ARCH_SAM) || defined(ARDUINO_ARCH_SAMD)
typedef Uart SerialType;
#define ENABLE_SLEEP
#else
typedef Stream SerialType;
#endif

// Available error codes.
enum MacTransmitErrorCodes
{
    NoError = 0,
    NoResponse = 1,
    Timeout = 2,
    PayloadSizeError = 3,
    InternalError = 4,
    Busy = 5,
    NetworkFatalError = 6,
    NotConnected = 7,
    NoAcknowledgment = 8,
};

// Provides a simple, abstracted interface to Microchip's RN2483 LoRaWAN module.
// Implements SwitchableDevice for turning the device On/Off on supported boards.
//
// It is strongly suggested to use the static instance that is included with the library (LoRaBee)
// and not to create a new instance.
class Sodaq_RN2483 : public SwitchableDevice
{
public:
    // Creates a new Sodaq_RN2483 instance.
    Sodaq_RN2483();

    // Returns the correct baudrate for the serial port that conneccts to the device.
    uint32_t getDefaultBaudRate() { return DEFAULT_BAUDRATE; };

    // Initializes the device and connects to the network using Over-The-Air Activation.
    // Returns true on successful setup for sendOTA.
    bool initOTA(SerialType& stream, const uint8_t devEUI[8], const uint8_t appEUI[8], const uint8_t appKey[16], bool adr = true);

	// sends the actual OTA request.
	bool sendOTA();
	
    // Initializes the device and connects to the network using Activation By Personalization.
    // Returns true on successful connection.
    bool initABP(SerialType& stream, const uint8_t devAddr[4], const uint8_t appSKey[16], const uint8_t nwkSKey[16], bool adr = true);

    // Sets the optional "Diagnostics and Debug" stream.
    void setDiag(Stream& stream) { diagStream = &stream; };

    // Sends the given payload without acknowledgement.
    // Returns 0 (NoError) when transmission is successful or one of the MacTransmitErrorCodes otherwise.
    uint8_t send(uint8_t port, const uint8_t* payload, uint8_t size);

    // Sends the given payload with acknowledgement.
    // Returns 0 (NoError) when transmission is successful or one of the MacTransmitErrorCodes otherwise.
    uint8_t sendReqAck(uint8_t port, const uint8_t* payload, uint8_t size, uint8_t maxRetries);

    // Copies the latest received packet (optionally starting from the "payloadStartPosition"
    // position of the payload) into the given "buffer", up to "size" number of bytes.
    // Returns the number of bytes written or 0 if no packet is received since last transmission.
    uint16_t receive(uint8_t* buffer, uint16_t size, uint16_t payloadStartPosition = 0);

    // Gets the preprogrammed EUI node address from the module.
    // Returns the number of bytes written or 0 in case of error.
    uint8_t getHWEUI(uint8_t* buffer, uint8_t size);

	// was private!!
    // Takes care of the init tasks common to both initOTA() and initABP.
	void init(SerialType& stream);


#ifdef ENABLE_SLEEP
    void wakeUp();

    void sleep();
#endif

#ifdef USE_DYNAMIC_BUFFER
    // Sets the size of the input buffer.
    // Needs to be called before initOTA()/initABP().
    void setInputBufferSize(uint16_t value) { this->inputBufferSize = value; };

    // Sets the size of the "Received Payload" buffer.
    // Needs to be called before initOTA()/initABP().
    void setReceivedPayloadBufferSize(uint16_t value) { this->receivedPayloadBufferSize = value; };
#endif

    // Provides a quick test of several methods as a pseudo-unit test.
    void runTestSequence(SerialType& loraStream, Stream& debugStream);
	
	
    // Sends a reset command to the module and waits for the success response (or timeout).
    // Returns true on success.
    bool resetDevice();
	
	bool setSpreadingFactor(uint8_t sf);

	bool setTXPower(int8_t power);	

	bool setDataRate(uint8_t dr);

private:
    // The stream that communicates with the device.
    SerialType* loraStream;

    // The (optional) stream to show debug information.
    Stream* diagStream;

    // The size of the input buffer. Equals DEFAULT_INPUT_BUFFER_SIZE
    // by default or (optionally) a user-defined value when using USE_DYNAMIC_BUFFER.
    uint16_t inputBufferSize;

    // The size of the received payload buffer. Equals DEFAULT_RECEIVED_PAYLOAD_BUFFER_SIZE
    // by default or (optionally) a user-defined value when using USE_DYNAMIC_BUFFER.
    uint16_t receivedPayloadBufferSize;

    // Flag used to make sure the received payload buffer is
    // current with the latest transmission.
    bool packetReceived;

	bool sleep_enabled = false;

#ifdef USE_DYNAMIC_BUFFER
    // Flag to make sure the buffers are not allocated more than once.
    bool isBufferInitialized;

    char* inputBuffer;
    char* receivedPayloadBuffer;
#else
    char inputBuffer[DEFAULT_INPUT_BUFFER_SIZE];
    char receivedPayloadBuffer[DEFAULT_RECEIVED_PAYLOAD_BUFFER_SIZE];
#endif

    // Reads a line from the device stream into the "buffer" starting at the "start" position of the buffer.
    // Returns the number of bytes read.
    uint16_t readLn(char* buffer, uint16_t size, uint16_t start = 0);

    // Reads a line from the device stream into the input buffer.
    // Returns the number of bytes read.
    uint16_t readLn() { return readLn(this->inputBuffer, this->inputBufferSize); };

    // Waits for the given string. Returns true if the string is received before a timeout.
    // Returns false if a timeout occurs or if another string is received.
    bool expectString(const char* str, uint16_t timeout = DEFAULT_TIMEOUT);
    bool expectOK();

	// function to ensure that the chip isnt sleeping
	void wakeUpIfSleeping();



    // Sends a join network command to the device and waits for the response (or timeout).
    // Returns true on success.
    bool joinNetwork(const char* type);

    // Enables all the channels that belong to the given Frequency Sub-Band (FSB)
    // and disables the rest.
    // fsb is [1, 8] or 0 to enable all channels.
    // Returns true if all channels were set successfully.
    bool setFsbChannels(uint8_t fsb);

    // Sends the given mac command together with the given paramValue
    // to the device and awaits for the response.
    // Returns true on success.
    // NOTE: paramName should include a trailing space
    bool setMacParam(const char* paramName, const uint8_t* paramValue, uint16_t size);
    bool setMacParam(const char* paramName, uint8_t paramValue);
    bool setMacParam(const char* paramName, const char* paramValue);

    // Returns the enum that is mapped to the given "error" message.
    uint8_t lookupMacTransmitError(const char* error);

    // Sends a a payload and blocks until there is a response back, or the receive windows have closed,
    // or the hard timeout has passed.
    uint8_t macTransmit(const char* type, uint8_t port, const uint8_t* payload, uint8_t size);

    // Parses the input buffer and copies the received payload into the "received payload" buffer
    // when a "mac rx" message has been received. It is called internally by macTransmit().
    // Returns 0 (NoError) or otherwise one of the MacTransmitErrorCodes.
    uint8_t onMacRX();
	bool setRadioParam(const char* paramName, const char* paramValue);
};

extern Sodaq_RN2483 LoRaBee;

#endif // Sodaq_RN2483

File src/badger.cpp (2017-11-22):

#include <Arduino.h>
//#include <EEPROM.h>

#include "LowPower_mod.h"
#include "SoftReset_mod.h"

#include "FaBoHumidity_HTS221_mod.h"


#include "badger.h"
#include "Sodaq_RN2483_mod.h"
#include "cayanneLPP.h"

//volatile bool sodaq_wdt_flag = false;

void sodaq_wdt_enable(wdt_period period)
{
	
	// From TPH_Demo/MyWatchdog.cpp
	// Both WDE and WDIE
	__asm__ __volatile__ (  \
						  "in __tmp_reg__,__SREG__" "\n\t"    \
						  "cli" "\n\t"    \
						  "wdr" "\n\t"    \
						  "sts %0,%1" "\n\t"  \
						  "out __SREG__,__tmp_reg__" "\n\t"   \
						  "sts %0,%2" "\n\t" \
						  : /* no outputs */  \
						  : "M" (_SFR_MEM_ADDR(_WD_CONTROL_REG)), \
        "r" (_BV(_WD_CHANGE_BIT) | _BV(WDE)), \
        "r" ((uint8_t) (((period & 0x08) ? _WD_PS3_MASK : 0x00) | \
						_BV(WDE) | _BV(WDIE) | (period & 0x07)) ) \
						  : "r0"  \
						  );
}


// Resets the WDT counter
void sodaq_wdt_reset()
{
	
	// Using avr/wdt.h
	wdt_reset();
	
	// Should this be called once per interrupt,
	// or are we ok calling it with every reset?
	WDTCSR |= _BV(WDIE);	
}

//
void sodaq_wdt_safe_delay(uint32_t ms)
{
	sleep_wdt_approx(ms);
}

static uint64_t millis_offset = 0;

uint32_t badger_millis()
{
	// overflow has to be considered..
	return millis() + millis_offset;
}

void sleep_wdt(period_t period, uint16_t period_ms, uint32_t* remainder)
{
	uint16_t divider = *remainder / period_ms;
	for(uint16_t i = 0; i < divider; i++)
	{
		if(badger_usb_powered())
		{
			delay(period_ms);
		}
		else
		{
			LowPower.powerDown(period, ADC_OFF, BOD_ON);
			millis_offset += period_ms;
		}
		*remainder = *remainder - period_ms;
	}
}

void sleep_wdt_approx(uint32_t sleep_time_ms)
{
	// guarantees no sleep after boot for usb to wake
	if(badger_usb_powered()) // || millis() < 6000)
	{
		delay(sleep_time_ms);
		return;
	}
	// since WDT oscillator accuracy is extremely low, compensating for sleep leftovers (<15ms) makes no sense. 
	if(sleep_time_ms < 60)
	{
		sleep_wdt(SLEEP_30MS, 30, &sleep_time_ms);	
		sleep_wdt(SLEEP_15MS, 15, &sleep_time_ms);
		delay(sleep_time_ms);
		return;
	}
	sleep_wdt(SLEEP_8S, 8000, &sleep_time_ms);
	sleep_wdt(SLEEP_4S, 4000, &sleep_time_ms);
	sleep_wdt(SLEEP_2S, 2000, &sleep_time_ms);
	sleep_wdt(SLEEP_1S, 1000, &sleep_time_ms);
	sleep_wdt(SLEEP_500MS, 500, &sleep_time_ms);
	sleep_wdt(SLEEP_250MS, 250, &sleep_time_ms);  
	sleep_wdt(SLEEP_120MS, 120, &sleep_time_ms);
	sleep_wdt(SLEEP_60MS, 60, &sleep_time_ms);
	sleep_wdt(SLEEP_30MS, 30, &sleep_time_ms);
	sleep_wdt(SLEEP_15MS, 15, &sleep_time_ms);
}


// Boot message
const uint8_t bootMSG[] =
{
	0xFF, 0xFF, 0xFF, 0xAB, 0xBA
};

const uint8_t reOTAA[] =
{
	0xFF, 0xFF, 0xFF, 0xBE, 0xEF
};

static uint32_t s_tx_last_time = 0;
static uint32_t s_tx_interval_min = 30000;

static uint32_t s_tx_successful_count = 0;
static uint32_t s_tx_failed_count = 0;

static bool s_LoRa_down = false;

bool Lora_tx_ready()
{
	return badger_millis() - s_tx_last_time < s_tx_interval_min ? false : true;
}

void Lora_down_check(bool success)
{
	static uint16_t s_failed_packets = 0;
	s_failed_packets++;
	if(success == true)
	{
		s_failed_packets = 0;
		s_LoRa_down = false;
	}
	if(s_failed_packets > 10)
	{
#ifdef	SERIAL_DEBUG	
		Serial.println(F("Too many failed packets. should restart!"));
#endif
		s_LoRa_down = true;
	}
}

void Lora_transmit_counter(bool success)
{
	if(success)
	{
		s_tx_successful_count++;
	}
	else
	{
		s_tx_failed_count++;
	}
	Lora_down_check(success);
}

bool Lora_requires_reset()
{
	return s_LoRa_down;
}

void badger_reset_lora()
{
	pinMode(LORA_RESET_PIN, OUTPUT);
	digitalWrite(LORA_RESET_PIN, LOW);
	sleep_wdt_approx(15);
	digitalWrite(LORA_RESET_PIN, HIGH);
}

bool LoRa_add_sensitivity(uint8_t sensitivity)
{
	LoRaBee.wakeUp();
	LoRaBee.wakeUp();
	sensitivity = sensitivity - 1;					
	if(sensitivity > 6)
		sensitivity = 6;
	sensitivity = 5 - sensitivity;
	Serial.print("Lora: Adding sensitivity: SF ");
	Serial.println(12 - sensitivity);
	bool ok = LoRaBee.setSpreadingFactor(12 - sensitivity);
	ok = LoRaBee.setTXPower(15) && ok;
	ok = LoRaBee.setDataRate(sensitivity) && ok;
	return ok;
	}


void LoRa_init_sleep()
{
	badger_reset_lora();
	loraSerial.begin(DEFAULT_BAUDRATE);
	LoRaBee.init(loraSerial);
	LoRaBee.wakeUp();
	LoRaBee.resetDevice();
	LoRaBee.sleep();
}

//void LoRa_sleep()
//{
//	LoRaBee.sleep();
//}

bool LoRa_init(const uint8_t dev_EUI[8], const uint8_t app_EUI[8], const uint8_t app_Key[16],bool adr)

{
	LoRaBee.setDiag(Serial);

    if(LoRaBee.initOTA(loraSerial, dev_EUI, app_EUI, app_Key, adr) == false)
	{
		badger_reset_lora();
		sleep_wdt_approx(1 * 1000UL);
		if(LoRaBee.initOTA(loraSerial, dev_EUI, app_EUI, app_Key, adr) == false)
		{
			badger_restart();
			sleep_wdt_approx(4000);
			return false;
		}
	}

	bool success = false;
	int i = 0;
	while(i <= 4)
	{
		if (LoRaBee.sendOTA() == true)
		{
			LoRaBee.sleep();
			s_tx_last_time = badger_millis();
#ifdef	SERIAL_DEBUG
			Serial.println(F("OTAA successful."));
#endif
			sleep_wdt_approx(12 * 1000UL);
			bool boot_msg_success = LoRa_send(99, bootMSG, 5, 4);
			int u = 0;
			while(!boot_msg_success && u++ < 4)
			{
				while(!Lora_tx_ready())
				{
					sleep_wdt_approx(4 * 1000UL);
					
				}
				
				boot_msg_success = LoRa_resend_try();
			}
			success = boot_msg_success;
			break;
		}
		else
		{
			LoRa_add_sensitivity(i);
			LoRaBee.sleep();
			badger_pulse_led(45);	
			sleep_wdt_approx(60);	  
			badger_pulse_led(45);
			sleep_wdt_approx(10000UL * (i + 1));
			i++;
		}
	}
	if(success == false)
	{
		sleep_wdt_approx(32000);
#ifdef	SERIAL_DEBUG
		Serial.println(F("Booting failed."));
#endif
		badger_restart();
		sleep_wdt_approx(4000);
		return false;
	}
#ifdef	SERIAL_DEBUG
	Serial.println(F("Boot msg sent. "));	
#endif
	s_tx_interval_min = 20000UL * (1 << i);
	badger_pulse_led(10);
	sleep_wdt_approx(60);
	badger_pulse_led(10);
	sleep_wdt_approx(60);
	badger_pulse_led(10);
	sleep_wdt_approx(60);
	badger_pulse_led(10);
	sleep_wdt_approx(60);
	badger_pulse_led(10);
	return success;
}

bool LoRa_initABP(const uint8_t devAddr[4], const uint8_t appSKey[16], const uint8_t nwkSKey[16], bool adr)			
{
	LoRaBee.setDiag(Serial);
	
    if(LoRaBee.initABP(loraSerial, devAddr, appSKey, nwkSKey, adr) == false)
	{
		badger_restart();
		sleep_wdt_approx(4000);
		return false;
	}
	LoRaBee.sleep();
	bool boot_msg_success = LoRa_send(99, bootMSG, 5, 4);
	int u = 0;
	while(!boot_msg_success && u++ < 4)
	{
		while(!Lora_tx_ready())
		{
			sleep_wdt_approx(4 * 1000UL);
		}
		boot_msg_success = LoRa_resend_try();
	}
	return boot_msg_success;
}

struct resend_data
{
	uint8_t fPort = 0;
	uint8_t data[LORA_TX_BUF_LEN_MAX];
	uint8_t len = 0;
	uint8_t count = 0;
} s_resend_data;
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

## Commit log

2017-02-21 Move to schematics
    [BB-M-1_0.brd]
2017-05-25 fixed wdt timing issue
    [Sodaq_RN2483_mod.cpp, badger.cpp]
2017-11-22 changed adr in init functions to variables instead of fixed values
    [LoRa_sf_change.ino, Lora_temp_hum.ino, badger.cpp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]

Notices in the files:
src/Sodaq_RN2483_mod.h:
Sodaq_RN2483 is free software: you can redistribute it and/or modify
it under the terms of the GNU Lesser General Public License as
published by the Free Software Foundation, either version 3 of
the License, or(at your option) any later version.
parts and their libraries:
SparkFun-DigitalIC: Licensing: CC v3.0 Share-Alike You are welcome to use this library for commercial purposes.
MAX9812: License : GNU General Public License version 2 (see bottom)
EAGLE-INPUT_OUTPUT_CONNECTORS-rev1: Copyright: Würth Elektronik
